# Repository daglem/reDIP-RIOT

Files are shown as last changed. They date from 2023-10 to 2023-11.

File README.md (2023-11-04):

# reDIP RIOT

## MOS 6530 RRIOT / MOS 6532 RIOT FPGA replacement
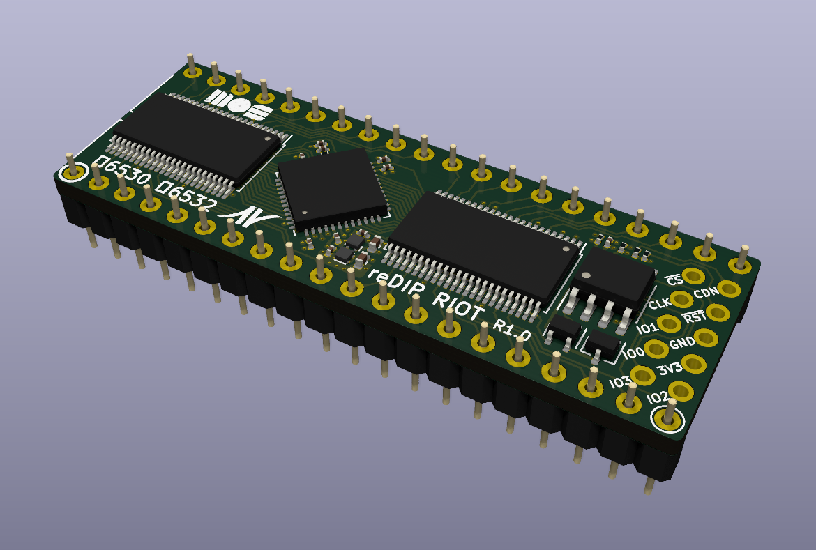
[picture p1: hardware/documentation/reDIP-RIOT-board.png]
Board


## Overview
The reDIP RIOT is an open source FPGA board which combines the following in a DIP-40 size package:

* Lattice iCE40UP5K FPGA
* 1Mbit FLASH
* 5V tolerant I/O

The reDIP RIOT provides an open source hardware platform for 6530 RRIOT / MOS 6532 RIOT replacements.

Designs for the iCE40UP5K FPGA can be processed by [yosys](https://github.com/YosysHQ/yosys/) and [nextpnr](https://github.com/YosysHQ/nextpnr/).

## I/O interfaces

### DIP-40 header pins:

* 5V input
* 35 FPGA GPIO
* 3 FPGA open-drain I/O
* GND

All FPGA header I/O is 5V tolerant, and can drive 5V TTL.

### SPI / programming header:

A separate header footprint is provided for (Q)SPI flash programming, with pinout borrowed from the [iCEBreaker Bitsy](https://github.com/icebreaker-fpga/icebreaker).

## Board Front
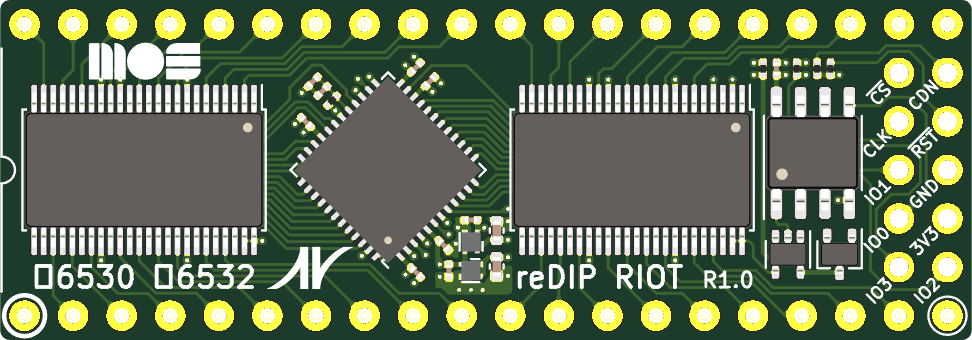
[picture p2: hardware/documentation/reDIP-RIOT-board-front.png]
Board Front


## Board Back
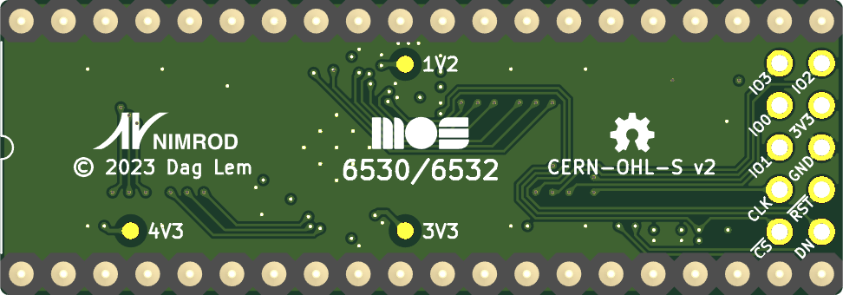
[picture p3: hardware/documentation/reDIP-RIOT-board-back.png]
Board Back


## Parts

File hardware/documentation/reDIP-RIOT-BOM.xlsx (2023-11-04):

Prj: | reDIP RIOT |  |  |  |  |  |  | Board Qty: | 100
Co.: | Nimrod |  |  |  |  |  |  | Unit Cost: | $9.44
Prj date: | Sat 04 Nov 2023 08:29:48 AM CET |  |  |  |  |  |  | Total Cost: | $944.10 |  |  |  |  | $961.94 | 13 of 15 parts found |  |  |  |  | $949.90 | 14 of 15 parts found
$ date: | 2023-11-04 08:29:49
Global Part Info |  |  |  |  |  |  |  |  |  | Digi-Key |  |  |  |  |  | Mouser
Refs | Value | Desc | Notes | Footprint | Manf | Manf# | Qty | Unit$ | Ext$ | Avail | Purch | Unit$ | MOQ | Ext$ | Cat# | Avail | Purch | Unit$ | MOQ | Ext$ | Cat#
C1,C3 | 1uF | CAP CER 2.2uF 16V 10% X6S 0402 | 5V DC DERATED TO 1uF | C_0402_1005Metric | Murata | GRM155C81C225KE11D (https://www.murata.com/products/productdetail.aspx?partno=GRM155C81C225KE11D) | 200 | $0.088 | $17.66 | 66508 |  | $0.088 | 1 | $17.66 | 490-14595-1-ND (https://www.digikey.com/en/products/detail/murata-electronics/GRM155C81C225KE11D/4905093) | 57211 |  | $0.089 | 1 | $17.80 | 81-GRM155C81C225KE1D (https://no.mouser.com/ProductDetail/Murata-Electronics/GRM155C81C225KE11D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)
C2,C11 | 1uF | CAP CER 1uF 6.3V 20% X6S 0201 | 1.2V DC | C_0201_0603Metric | Murata | GRM033C80J105ME05D (https://www.murata.com/products/productdetail.aspx?partno=GRM033C80J105ME05D) | 200 | $0.054 | $10.80 | 1440111 |  | $0.078 | 1 | $15.56 | 490-13218-1-ND (https://www.digikey.com/en/products/detail/murata-electronics/GRM033C80J105ME05D/5877381) | 777764 |  | $0.054 | 1 | $10.80 | 81-GRM033C80J105ME5D (https://no.mouser.com/ProductDetail/Murata-Electronics/GRM033C80J105ME05D?qs=P8zzrVhehaso8Xg5mhsu3Q%3D%3D)
C4 | 1uF | CAP CER 2.2uF 10V 20% X5R 0201 | 3.3V DC DERATED TO 1uF | C_0201_0603Metric | Murata | GRM035R61A225ME01D (https://www.murata.com/products/productdetail.aspx?partno=GRM035R61A225ME01D) | 100 |  |  |  |  |  |  |  |  | NonStk |  |  | 10000 |  | 81-GRM035R61A225ME1D (https://no.mouser.com/ProductDetail/Murata-Electronics/GRM035R61A225ME01D?qs=pUKx8fyJudAGsIsikE8KgA%3D%3D)
C5-C10,C12 | 0.1uF | CAP CER 0.22uF 6.3V 20% X5R 0201 | C8: 1.2V DC DERATED TO 0.1uF C5-C7,C9,C10,C12: 3.3V DC DERATED TO 0.1uF | C_0201_0603Metric | Murata | GRM033R60J224ME90D (https://www.murata.com/products/productdetail.aspx?partno=GRM033R60J224ME90D) | 700 | $0.006 | $4.24 | 14729 |  | $0.006 | 1 | $4.24 | 490-11973-1-ND (https://www.digikey.com/en/products/detail/murata-electronics/GRM033R60J224ME90D/4904674) | 84464 |  | $0.007 | 1 | $4.90 | 81-GRM033R60J224ME9D (https://no.mouser.com/ProductDetail/Murata-Electronics/GRM033R60J224ME90D?qs=2W5sgKM%2F3704nCcQ8ai7mA%3D%3D)
D1 | BAS16W | DIODE Vf=715mV If=1mA | Replacement parts: BAS16W SOT-323/SC-70 | SOT-323_SC-70 | Diodes | BAS16W-7-F (https://www.diodes.com/assets/Datasheets/MMBD4148W_BAS16W.pdf) | 100 | $0.057 | $5.70 | 43800 |  | $0.073 | 1 | $7.33 | BAS16W-FDICT-ND (https://www.digikey.com/en/products/detail/diodes-incorporated/BAS16W-7-F/814988) | 21552 |  | $0.057 | 1 | $5.70 | 621-BAS16W-F (https://no.mouser.com/ProductDetail/Diodes-Incorporated/BAS16W-7-F?qs=Kn7RVldD90CMqWoFVqNeZQ%3D%3D)
J1,J2 | Conn_01x20 | CONN HDR CIRCULAR PIN 0.5mm 20 POS .100" GOLD MATING 3mm TAIL 3mm | Replacement parts: XKB X5511WV-20-C396D43-1220, other similar hdr circular pin ~0.5mm | PinHeader_1x20_P2.54mm_Vertical_Machined | XKB | X5511WV-20-C35D35-1000 (https://www.helloxkb.com/Home/Goods/goodsInfo/id/72370.html) | 200
R1,R5 | 2.87k | RES 2.87kΩ 50mW 1% 0201 |  | R_0201_0603Metric | Panasonic | ERJ1GNF2871C (https://industrial.panasonic.com/ww/products/pt/general-purpose-chip-resistors/models/ERJ1GNF2871C) | 200 | $0.014 | $2.80 | 104225 |  | $0.019 | 1 | $3.80 | P122901CT-ND (https://www.digikey.com/en/products/detail/panasonic-electronic-components/ERJ-1GNF2871C/2036162) | 28194 |  | $0.014 | 1 | $2.80 | 667-ERJ-1GNF2871C (https://no.mouser.com/ProductDetail/Panasonic/ERJ-1GNF2871C?qs=nuXzIS8loXEy0KxXtNZxEA%3D%3D)
R2 | 100 | RES 100Ω 50mW 5% 0201 |  | R_0201_0603Metric | Panasonic | ERJ1GNJ101C (https://industrial.panasonic.com/ww/products/pt/general-purpose-chip-resistors/models/ERJ1GNJ101C) | 100 | $0.007 | $0.70 | 231675 |  | $0.013 | 1 | $1.25 | P123220CT-ND (https://www.digikey.com/en/products/detail/panasonic-electronic-components/ERJ-1GNJ101C/2035763) | 91154 |  | $0.007 | 1 | $0.70 | 667-ERJ-1GNJ101C (https://no.mouser.com/ProductDetail/Panasonic/ERJ-1GNJ101C?qs=nuXzIS8loXGN5So4aOOV1Q%3D%3D)
R3,R4 | 10k | RES 10kΩ 50mW 1% 0201 |  | R_0201_0603Metric | Panasonic | ERJ1GNF1002C (https://industrial.panasonic.com/ww/products/pt/general-purpose-chip-resistors/models/ERJ1GNF1002C) | 200 | $0.014 | $2.80 | 2247581 |  | $0.019 | 1 | $3.80 | P122414CT-ND (https://www.digikey.com/en/products/detail/panasonic-electronic-components/ERJ-1GNF1002C/2036226) | 2408384 |  | $0.014 | 1 | $2.80 | 667-ERJ-1GNF1002C (https://no.mouser.com/ProductDetail/Panasonic/ERJ-1GNF1002C?qs=nuXzIS8loXE96jG2vMMQNw%3D%3D)
U1 | NCP115AMX120TCG | IC REG LDO 1.2V 300mA XDFN4 |  | CASE_711AJ_1.0x1.0mm_P0.65mm | onsemi | NCP115AMX120TCG (https://www.onsemi.com/pdf/datasheet/ncp115-d.pdf) | 100 | $0.118 | $11.80 | 7412 |  | $0.143 | 1 | $14.33 | NCP115AMX120TCGOSCT-ND (https://www.digikey.com/en/products/detail/onsemi/NCP115AMX120TCG/9829201) | 11436 |  | $0.118 | 1 | $11.80 | 863-NCP115AMX120TCG (https://no.mouser.com/ProductDetail/onsemi/NCP115AMX120TCG?qs=l7cgNqFNU1iSEavmMXBgHw%3D%3D)
U2 | NCP115AMX330TCG | IC REG LDO 3.3V 300mA XDFN4 |  | CASE_711AJ_1.0x1.0mm_P0.65mm | onsemi | NCP115AMX330TCG (https://www.onsemi.com/pdf/datasheet/ncp115-d.pdf) | 100 | $0.124 | $12.40 | 12836 |  | $0.143 | 1 | $14.33 | NCP115AMX330TCGOSCT-ND (https://www.digikey.com/en/products/detail/onsemi/NCP115AMX330TCG/9829207) | 26927 |  | $0.124 | 1 | $12.40 | 863-NCP115AMX330TCG (https://no.mouser.com/ProductDetail/onsemi/NCP115AMX330TCG?qs=l7cgNqFNU1j9mIi8Ii%2FRXw%3D%3D)
U3,U4 | SN74CBT16210CDGGR | IC BUS SWITCH TSSOP-48 | Replacement parts: SN74CBT16210DGGR | TSSOP-48_6.1x12.5mm_P0.5mm | TI | SN74CBT16210CDGGR (https://www.ti.com/lit/ds/symlink/sn74cbt16210c.pdf) | 200 |  |  | 20045 |  |  | 502 |  | 2156-SN74CBT16210CDGGR-ND (https://www.digikey.com/en/products/detail/texas-instruments/SN74CBT16210CDGGR/864166) | NonStk |  |  | 2000 |  | 595-SN74CBT16210CDGG (https://no.mouser.com/ProductDetail/Texas-Instruments/SN74CBT16210CDGGR?qs=PVVDbbWpW3LUOtG5S0DQpQ%3D%3D)
U5 | 74AHCT1G14 | IC SCHMITT-TRIGGER INVERTER | Replacement parts: 74AHCT1G14 SOT-353/SC-70-5 | SOT-353_SC-70-5 | Diodes | 74AHCT1G14SE-7 (https://www.diodes.com/assets/Datasheets/74AHCT1G14.pdf) | 100 | $0.077 | $7.70 | 74194 |  | $0.118 | 1 | $11.80 | 74AHCT1G14SE-7DICT-ND (https://www.digikey.com/en/products/detail/diodes-incorporated/74AHCT1G14SE-7/2711985) | 1287 |  | $0.077 | 1 | $7.70 | 621-74AHCT1G14SE-7 (https://no.mouser.com/ProductDetail/Diodes-Incorporated/74AHCT1G14SE-7?qs=MKoP7Oyr0W4E9AvHvgTtWw%3D%3D)
U6 | ICE40UP5K-SG48 | IC FPGA QFN-48 |  | QFN-48-1EP_7x7mm_P0.5mm_EP5.6x5.6mm | Lattice | ICE40UP5K-SG48I (http://www.latticesemi.com/Products/FPGAandCPLD/iCE40Ultra) | 100 | $8.450 | $845.00 | NonStk |  | $8.450 | 1 | $845.00 | 220-2212-1-ND (https://www.digikey.com/en/products/detail/lattice-semiconductor-corporation/ICE40UP5K-SG48I/7785190) | 12647 |  | $8.500 | 1 | $850.00 | 842-ICE40UP5K-SG48I (https://no.mouser.com/ProductDetail/Lattice/ICE40UP5K-SG48I?qs=Rp3RbKSfAt3UqOG1AN4%2FAg%3D%3D)
U7 | AT25EU0011A-SSHN | IC FLASH 1MBIT | Replacement parts: 1MBit SPI flash SOIC-8/SOP-8 | SOIC-8_3.9x4.9mm_P1.27mm | Renesas | AT25EU0011A-SSHN-T (https://www.renesas.com/us/en/document/dst/at25eu0011a-datasheet) | 100 | $0.225 | $22.50 | 3995 |  | $0.228 | 1 | $22.84 | 1695-AT25EU0011A-SSHN-TCT-ND (https://www.digikey.com/en/products/detail/renesas-electronics-operations-services-limited/AT25EU0011A-SSHN-T/14309093) | 3935 |  | $0.225 | 1 | $22.50 | 724-AT25EU0011ASSHNT (https://no.mouser.com/ProductDetail/Renesas-Dialog/AT25EU0011A-SSHN-T?qs=QNEnbhJQKvbVoO3jTCIuvg%3D%3D)
 |  |  |  |  |  |  |  | Total Purchase: | $0.00 | Buy here (https://www.digikey.com/ordering/shoppingcart) |  |  |  | $0.00 |  | Buy here (https://mouser.com/bom/) |  |  |  | $0.00
KiCost® v1.1.18 |  |  |  |  |  |  |  | Purchase description:

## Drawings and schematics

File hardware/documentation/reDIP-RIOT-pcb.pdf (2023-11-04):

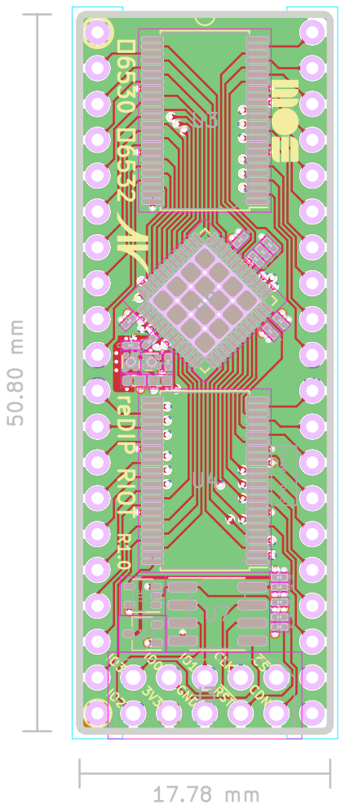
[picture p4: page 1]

UL and date code J1J2 TP1 TP3 TP2 þÿ©2023 Dag Lem 1V2 CERN-OHL-S v2 IO1 3V3 GND~{RST} CDN IO0 CLK ~{CS} IO2 IO3 3V3 4V3 6530/6532 reDIP RIOT IO2 3V3 CDN IO1GND CLK R1.0 ~{CS} þÿ&6530þÿ&6532 IO3 IO0 ~{RST} Date code

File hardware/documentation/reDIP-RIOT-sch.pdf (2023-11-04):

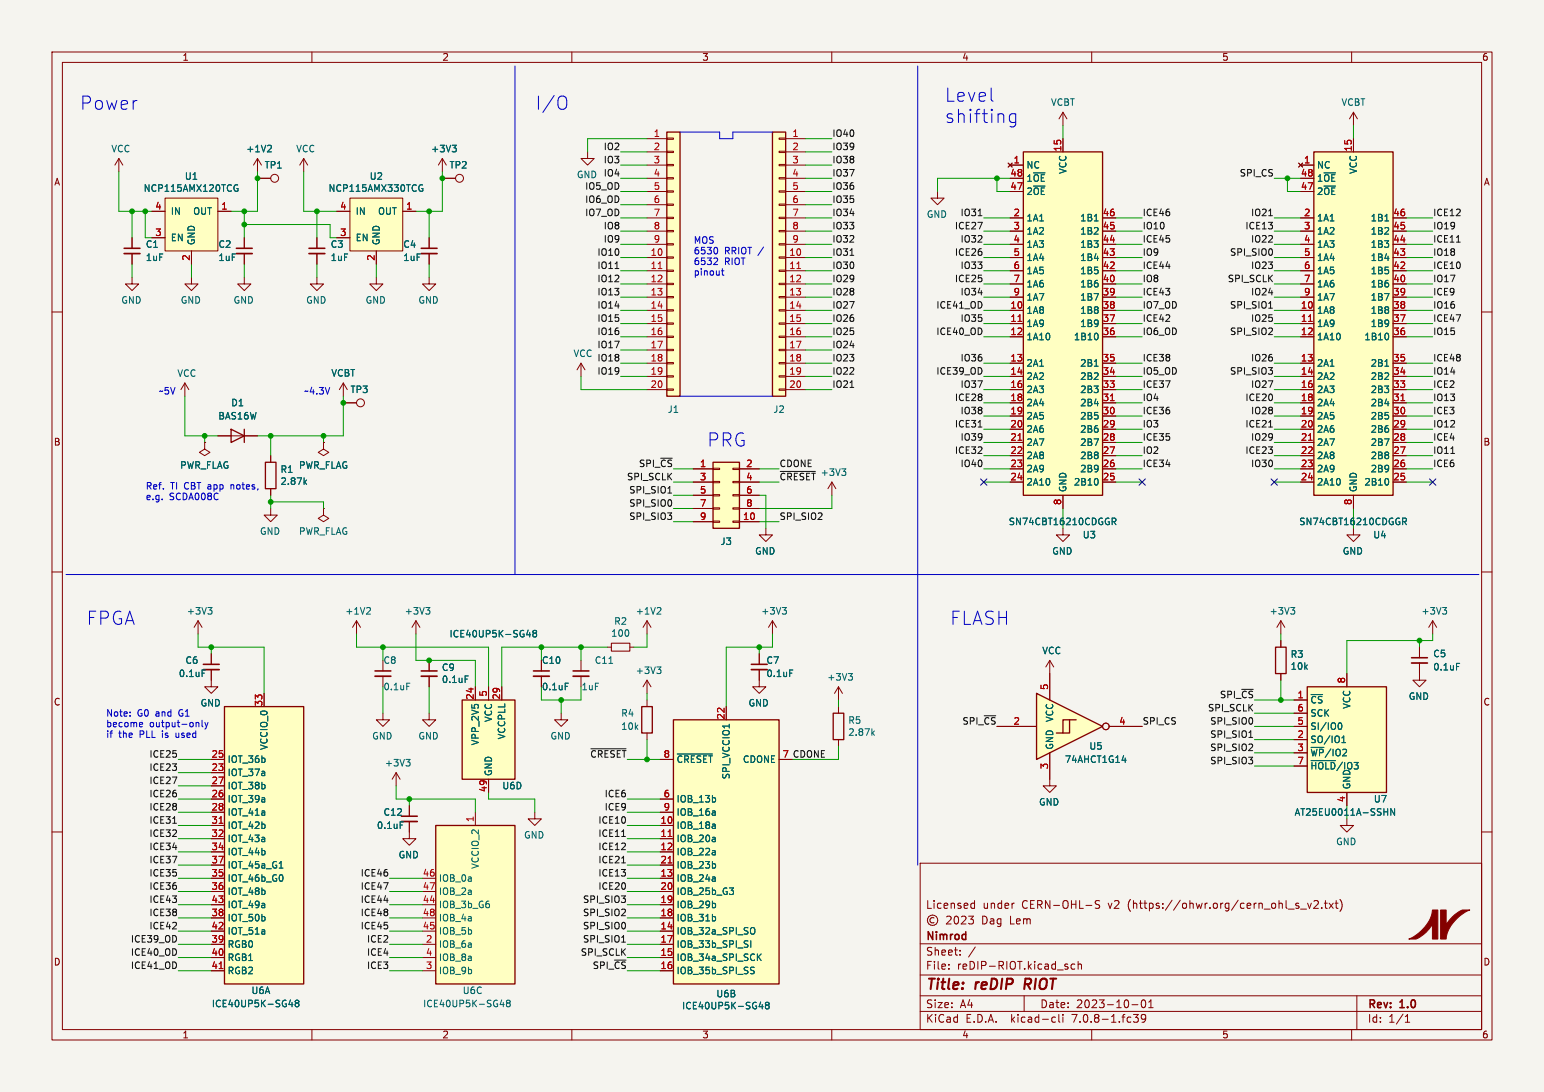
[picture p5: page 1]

4 SI/IO0 5 SCK 6 ~{HOLD}/IO3 7 VCC

File: reDIP-RIOT.kicad_sch Sheet: / Nimrod

Id: 1/1 Title: reDIP RIOT

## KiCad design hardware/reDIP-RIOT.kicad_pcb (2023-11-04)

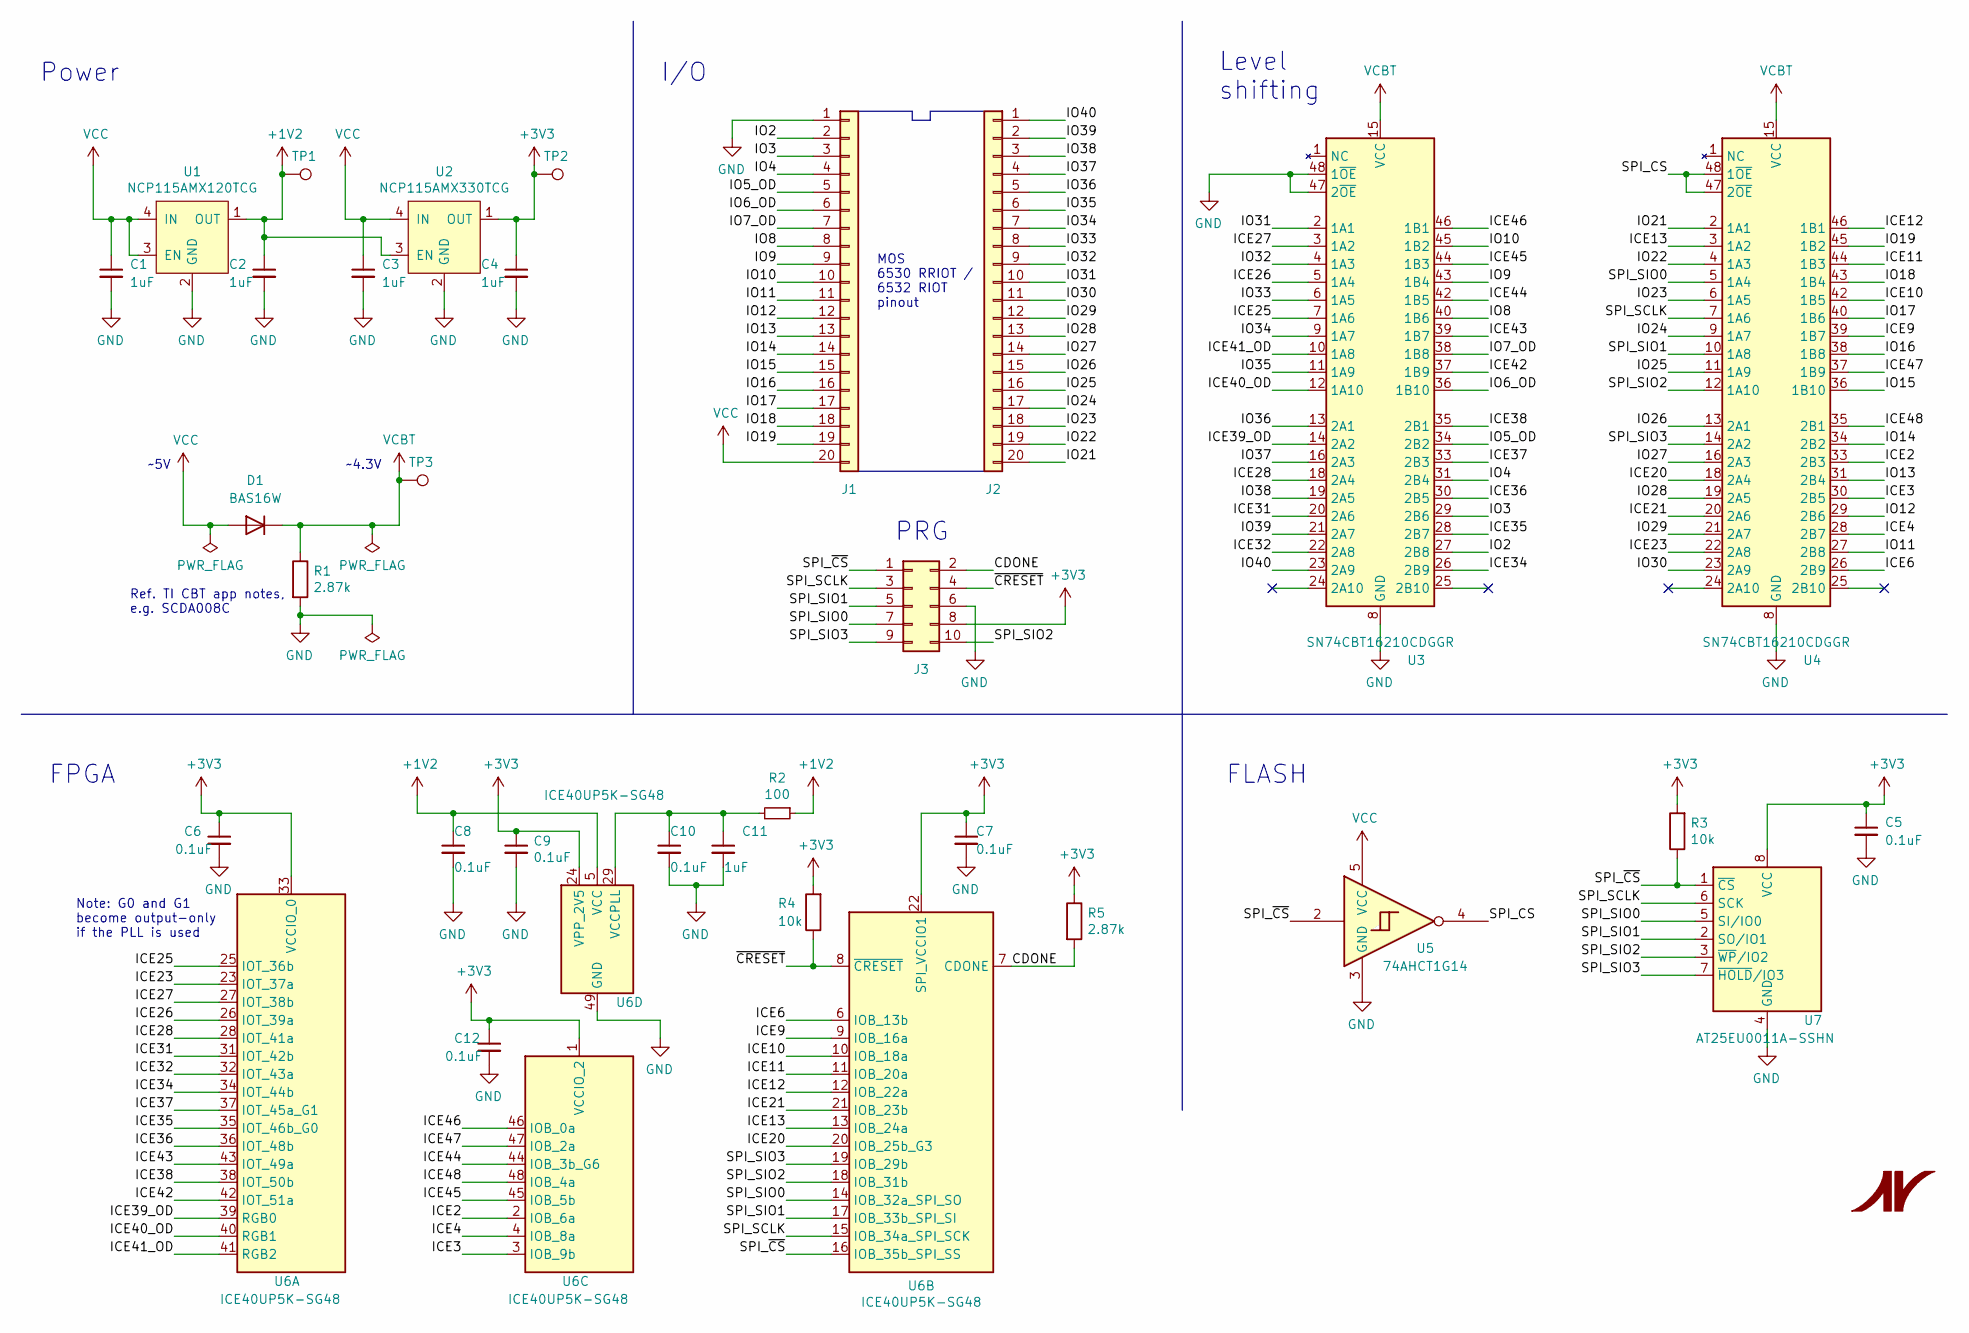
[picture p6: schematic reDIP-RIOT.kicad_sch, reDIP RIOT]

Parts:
C1, C3: 1uF; C_0402_1005Metric
C2, C4, C11: 1uF; C_0201_0603Metric
C5, C6, C7, C8, C9, C10, C12: 0.1uF; C_0201_0603Metric
D1: BAS16W; SOT-323_SC-70
J1, J2: Conn_01x20; PinHeader_1x20_P2.54mm_Vertical_Machined
J3: Conn_02x05_Odd_Even; PinHeader_2x05_P2.54mm_Vertical
R1, R5: 2.87k; R_0201_0603Metric
R2: 100; R_0201_0603Metric
R3, R4: 10k; R_0201_0603Metric
TP1, TP2, TP3: TestPoint; TestPoint_Pad_D1.00mm
U1: NCP115AMX120TCG; CASE_711AJ_1.0x1.0mm_P0.65mm
U2: NCP115AMX330TCG; CASE_711AJ_1.0x1.0mm_P0.65mm
U3, U4: SN74CBT16210CDGGR; TSSOP-48_6.1x12.5mm_P0.5mm
U5: 74AHCT1G14; SOT-353_SC-70-5
U6: ICE40UP5K-SG48; QFN-48-1EP_7x7mm_P0.5mm_EP5.6x5.6mm
U7: AT25EU0011A-SSHN; SOIC-8_3.9x4.9mm_P1.27mm

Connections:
+1V2: C2.1, C8.1, R2.1, TP1.1, U1.1 (OUT), U2.3 (EN), U6.5 (VCC), U6.30 (VCC)
+3V3: C4.1, C5.1, C6.1, C7.1, C9.1, C12.1, J3.8, R3.2, R4.2, R5.1, TP2.1, U2.1 (OUT), U6.1 (VCCIO_2), U6.22 (SPI_VCCIO1), U6.24 (VPP_2V5), U6.33 (VCCIO_0), U7.8 (VCC)
/CDONE: J3.2, R5.2, U6.7 (CDONE)
/ICE2: U4.33 (2B3), U6.2 (IOB_6a)
/ICE3: U4.30 (2B5), U6.3 (IOB_9b)
/ICE4: U4.28 (2B7), U6.4 (IOB_8a)
/ICE6: U4.26 (2B9), U6.6 (IOB_13b)
/ICE9: U4.39 (1B7), U6.9 (IOB_16a)
/ICE10: U4.42 (1B5), U6.10 (IOB_18a)
/ICE11: U4.44 (1B3), U6.11 (IOB_20a)
/ICE12: U4.46 (1B1), U6.12 (IOB_22a)
/ICE13: U4.3 (1A2), U6.13 (IOB_24a)
/ICE20: U4.18 (2A4), U6.20 (IOB_25b_G3)
/ICE21: U4.20 (2A6), U6.21 (IOB_23b)
/ICE23: U4.22 (2A8), U6.23 (IOT_37a)
/ICE25: U3.7 (1A6), U6.25 (IOT_36b)
/ICE26: U3.5 (1A4), U6.26 (IOT_39a)
/ICE27: U3.3 (1A2), U6.27 (IOT_38b)
/ICE28: U3.18 (2A4), U6.28 (IOT_41a)
/ICE31: U3.20 (2A6), U6.31 (IOT_42b)
/ICE32: U3.22 (2A8), U6.32 (IOT_43a)
/ICE34: U3.26 (2B9), U6.34 (IOT_44b)
/ICE35: U3.28 (2B7), U6.35 (IOT_46b_G0)
/ICE36: U3.30 (2B5), U6.36 (IOT_48b)
/ICE37: U3.33 (2B3), U6.37 (IOT_45a_G1)
/ICE38: U3.35 (2B1), U6.38 (IOT_50b)
/ICE39_OD: U3.14 (2A2), U6.39 (RGB0)
/ICE40_OD: U3.12 (1A10), U6.40 (RGB1)
/ICE41_OD: U3.10 (1A8), U6.41 (RGB2)
/ICE42: U3.37 (1B9), U6.42 (IOT_51a)
/ICE43: U3.39 (1B7), U6.43 (IOT_49a)
/ICE44: U3.42 (1B5), U6.44 (IOB_3b_G6)
/ICE45: U3.44 (1B3), U6.45 (IOB_5b)
/ICE46: U3.46 (1B1), U6.46 (IOB_0a)
/ICE47: U4.37 (1B9), U6.47 (IOB_2a)
/ICE48: U4.35 (2B1), U6.48 (IOB_4a)
/IO2: J1.2, U3.27 (2B8)
/IO3: J1.3, U3.29 (2B6)
/IO4: J1.4, U3.31 (2B4)
/IO5_OD: J1.5, U3.34 (2B2)
/IO6_OD: J1.6, U3.36 (1B10)
/IO7_OD: J1.7, U3.38 (1B8)
/IO8: J1.8, U3.40 (1B6)
/IO9: J1.9, U3.43 (1B4)
/IO10: J1.10, U3.45 (1B2)
/IO11: J1.11, U4.27 (2B8)
/IO12: J1.12, U4.29 (2B6)
/IO13: J1.13, U4.31 (2B4)
/IO14: J1.14, U4.34 (2B2)
/IO15: J1.15, U4.36 (1B10)
/IO16: J1.16, U4.38 (1B8)
/IO17: J1.17, U4.40 (1B6)
/IO18: J1.18, U4.43 (1B4)
/IO19: J1.19, U4.45 (1B2)
/IO21: J2.20, U4.2 (1A1)
/IO22: J2.19, U4.4 (1A3)
/IO23: J2.18, U4.6 (1A5)
/IO24: J2.17, U4.9 (1A7)
/IO25: J2.16, U4.11 (1A9)
/IO26: J2.15, U4.13 (2A1)
/IO27: J2.14, U4.16 (2A3)
/IO28: J2.13, U4.19 (2A5)
/IO29: J2.12, U4.21 (2A7)
/IO30: J2.11, U4.23 (2A9)
/IO31: J2.10, U3.2 (1A1)
/IO32: J2.9, U3.4 (1A3)
/IO33: J2.8, U3.6 (1A5)
/IO34: J2.7, U3.9 (1A7)
/IO35: J2.6, U3.11 (1A9)
/IO36: J2.5, U3.13 (2A1)
/IO37: J2.4, U3.16 (2A3)
/IO38: J2.3, U3.19 (2A5)
/IO39: J2.2, U3.21 (2A7)
/IO40: J2.1, U3.23 (2A9)
/SPI_CS: U4.47 (2~OE), U4.48 (1~OE), U5.4
/SPI_SCLK: J3.3, U4.7 (1A6), U6.15 (IOB_34a_SPI_SCK), U7.6 (SCK)
/SPI_SIO0: J3.7, U4.5 (1A4), U6.14 (IOB_32a_SPI_SO), U7.5 (SI/IO0)
/SPI_SIO1: J3.5, U4.10 (1A8), U6.17 (IOB_33b_SPI_SI), U7.2 (SO/IO1)
/SPI_SIO2: J3.10, U4.12 (1A10), U6.18 (IOB_31b), U7.3 (~WP/IO2)
/SPI_SIO3: J3.9, U4.14 (2A2), U6.19 (IOB_29b), U7.7 (~HOLD/IO3)
/SPI_~CS: J3.1, R3.1, U5.2, U6.16 (IOB_35b_SPI_SS), U7.1 (~CS)
/~CRESET: J3.4, R4.1, U6.8 (~CRESET)
GND: C1.2, C2.2, C3.2, C4.2, C5.2, C6.2, C7.2, C8.2, C9.2, C10.2, C11.2, C12.2, J1.1, J3.6, R1.2, U1.2 (GND), U2.2 (GND), U3.8 (GND), U3.17 (GND), U3.32 (GND), U3.41 (GND), U3.47 (2~OE), U3.48 (1~OE), U4.8 (GND), U4.17 (GND), U4.32 (GND), U4.41 (GND), U5.3 (GND), U6.49 (GND), U7.4 (GND)
unnamed: C10.1, C11.1, R2.2, U6.29 (VCCPLL)
VCBT: D1.3 (K), R1.1, TP3.1, U3.15 (VCC), U4.15 (VCC)
VCC: C1.1, C3.1, D1.1 (A), J1.20, U1.3 (EN), U1.4 (IN), U2.4 (IN), U5.5 (VCC)

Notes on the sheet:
MOS 6530 RRIOT / 6532 RIOT pinout
PRG
Ref. TI CBT app notes, e.g. SCDA008C
~4.3V
FLASH
FPGA
Power
I/O
Level shifting
~5V
Note: G0 and G1 become output-only if the PLL is used

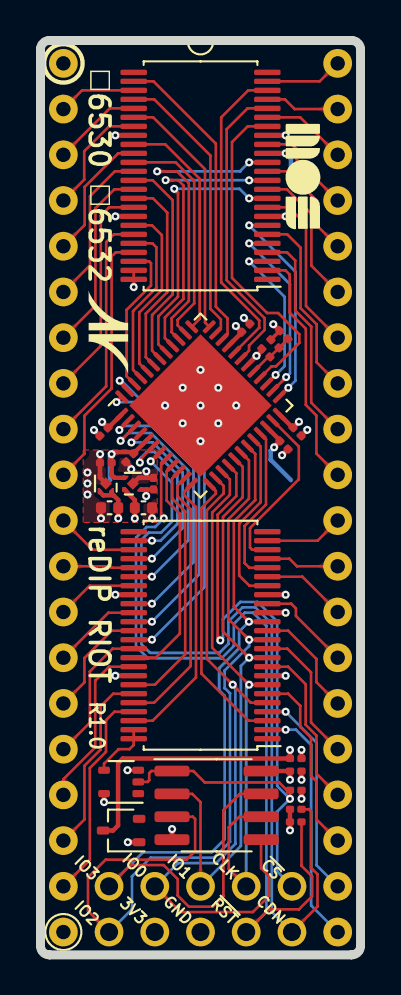
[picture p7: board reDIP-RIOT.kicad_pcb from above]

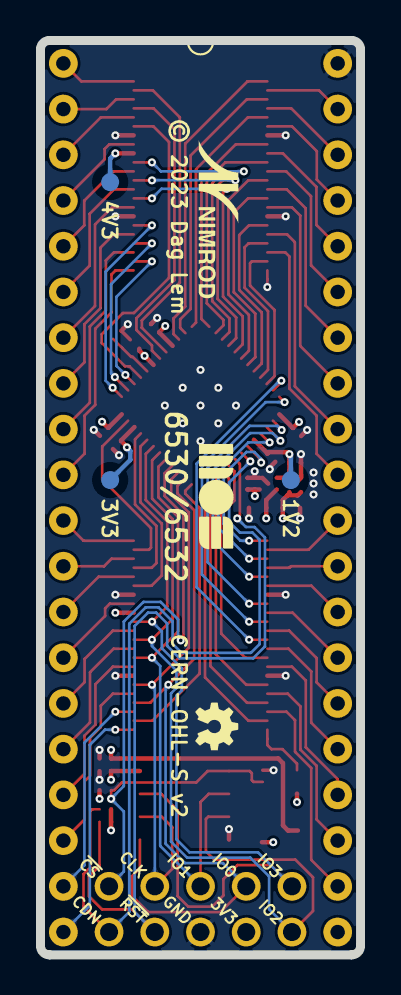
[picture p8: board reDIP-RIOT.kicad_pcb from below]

Board: 4 copper layers, 17.8 x 50.8 mm, 40 parts (14 on the bottom side), 86 nets.

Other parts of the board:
SolderMask_D0.25mm, SolderMask_D0.25mm#2, SolderMask_D0.25mm#3, SolderMask_D0.25mm#4, SolderMask_D0.25mm#5, SolderMask_D0.25mm#6, SolderMask_D0.25mm#7, SolderMask_D0.25mm#8, SolderMask_D0.25mm#9: SolderMask_D0.25mm

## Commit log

2023-10-02 Added CRESET pull-up, removed CDONE LED
    [reDIP-RIOT-BOM.xlsx, reDIP-RIOT.kicad_pcb, reDIP-RIOT.kicad_sch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]
2023-10-03 Cleanup
    * Removed unused footprints
    * Rounded rectangle pads for SOT footprints
    * Increased drill to 0.8mm for header pins
    * Corrected BOM text
    [reDIP-RIOT-BOM.xlsx, reDIP-RIOT.kicad_pcb, reDIP-RIOT.kicad_sch]
2023-10-04 Added example pin headers to BOM
    [reDIP-RIOT-BOM.xlsx, reDIP-RIOT.kicad_pcb, reDIP-RIOT.kicad_sch]
2023-10-06 LDO ground planes, via teardrops
    [reDIP-RIOT.kicad_pcb]
2023-10-06 Use 74AHCT1G14 for better signal level margins
    [reDIP-RIOT-BOM.xlsx, reDIP-RIOT.kicad_pcb, reDIP-RIOT.kicad_sch]
2023-10-09 Power supply for 74AHCT1G14 within range
    [reDIP-RIOT.kicad_pcb, reDIP-RIOT.kicad_sch]
2023-11-04 Replaced iCE5LP1K with iCE40UP5K
    The MOS 6530 and MOS 6532 have on-chip data port pull-up resistors
    in the range of 5k.
    While the iCE40UP5K features configurable 3.3k/6.8k/10k/100k pull-up
    resistors, the iCE5LP1K only features 100k pull-up resistors.
    We make the simple fix of using the more capable (and somewhat more
    expensive) pin compatible iCE40UP5K, instead of adding physical
    pull-up resistors to separate boards for the MOS 6530 and MOS 6532.
    [reDIP-RIOT-BOM.xlsx, reDIP-RIOT.kicad_pcb, reDIP-RIOT.kicad_sch]
2024-08-12 Add configuration for pull-up resistors

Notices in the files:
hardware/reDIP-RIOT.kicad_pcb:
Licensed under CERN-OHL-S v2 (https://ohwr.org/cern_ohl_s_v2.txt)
